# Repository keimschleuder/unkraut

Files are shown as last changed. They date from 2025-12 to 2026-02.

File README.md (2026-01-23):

# Jugend Forscht Unkrautvernichtungsroboter

Wir sind eine Gruppe von 4 Schülern aus Hessen (Deutschland). Wir haben im Rahmen einer Schul-Arbeitsgemeinschaft ein Projekt für den Wettbewerb [Jugend Forscht](https://www.jugend-forscht.de/) erarbeitet. 

## Das Projekt

Wir wollten es mit unserem Roboter ermöglichen, Herbizide und Dünger gezielt einzusetzten. 

Die Hoffnung war, dadurch den Herbizidverbrauch zu reduzieren. 

## Unsere Hardware

Wir verwendeten folgende Produkte: 

<sub>Keine Sponsoren oder sonst irgendwas</sub>

### Für den Raspberry Pi:
* [Raspberry Pi 5 16gb RAM](https://www.berrybase.de/raspberry-pi-5-16gb-ram)
* [Raspberry Pi Active Cooler](https://www.berrybase.de/raspberry-pi-active-cooler-luefter-fuer-raspberry-pi-5)
* [Raspberry Pi AI Camera](https://www.berrybase.de/raspberry-pi-ai-camera)
* [Raspberry Pi 27W Power Supply](https://www.berrybase.de/raspberry-pi-ai-camera)
* [Micro SD Karte](https://www.berrybase.de/sandisk-extreme-pro-microsdxc-a2-uhs-i-u3-v30-200mb-s-speicherkarte-adapter-256gb)

### Motoren und Ansteuerung
* [Arduino Nano](https://www.amazon.de/YELUFT-CH340G-Kompatibel-Arduino-Typ-C-Schnittstelle/dp/B0F5PZXH51)
* [2.2 Ohm 5W Widerstand](https://www.amazon.de/PATIKIL-Widerst%C3%A4nde-Widerstand-Netzadapter-Leiterplatte/dp/B0CS3F67QV)
* [Logic Level Converter](https://www.amazon.de/AZDelivery-TXS0108E-Converter-Arduino-Raspberry/dp/B07N7FFY2Q)
* [Servo-Treiber](https://www.amazon.de/AZDelivery-PCA9685-Servotreiber-Arduino-Raspberry/dp/B072N8G7Y9?th=1)
* [Relais](https://www.amazon.de/AZ822-2C-3DSE-Relais-elektromagnetisch-USpule-120VAC/dp/B01LZZPO4O)

## Schaltplan 

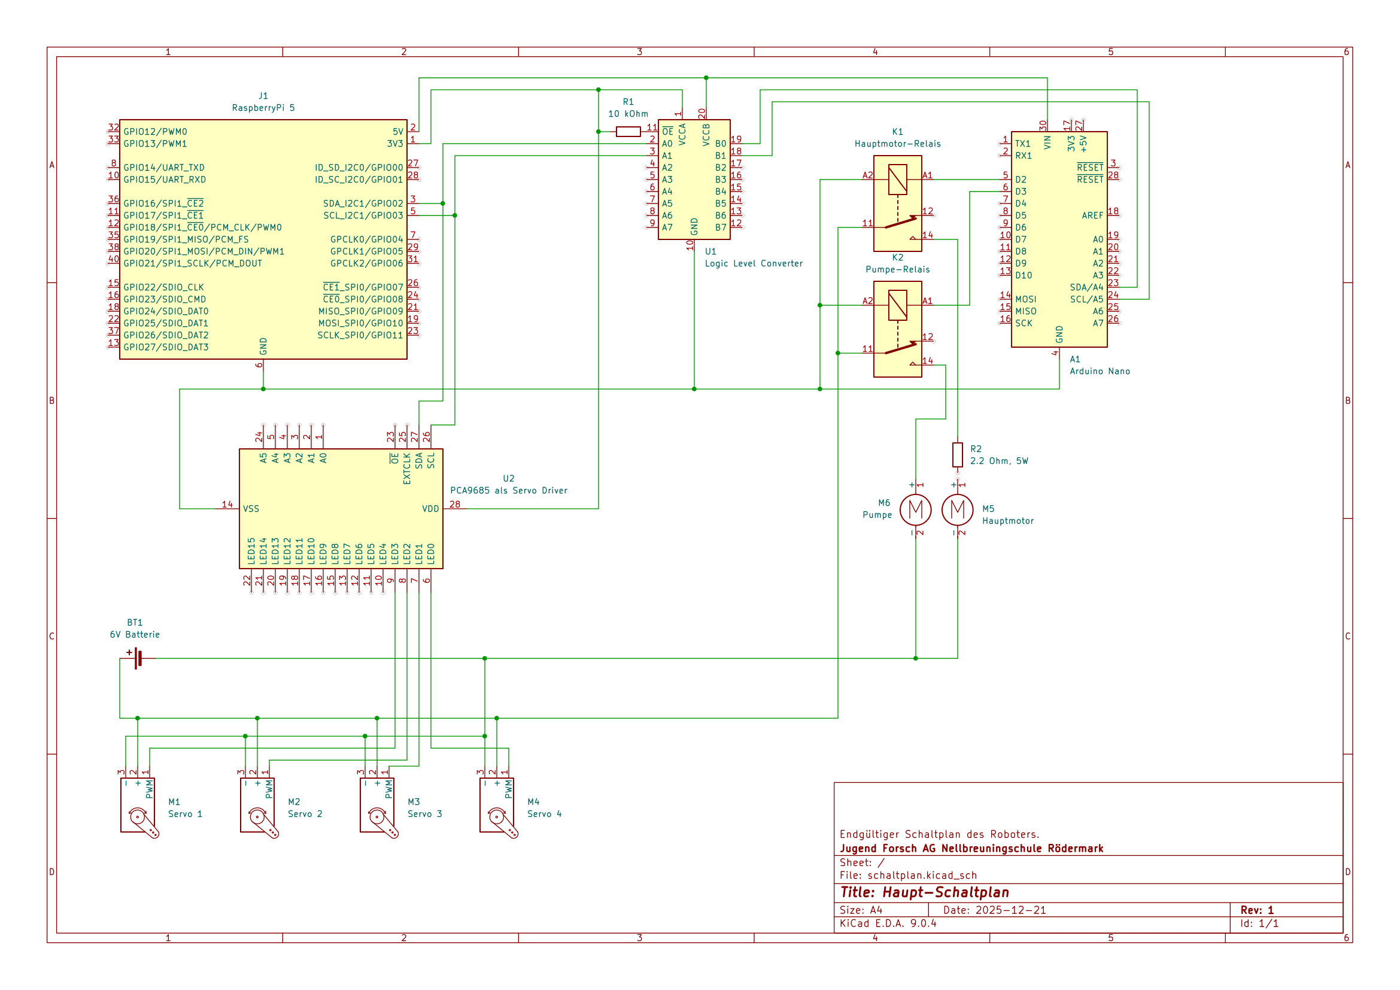
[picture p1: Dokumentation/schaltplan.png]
Schaltplan


## Zu Hause nachbauen

1. Wenn du alle Komponenten hast, installiere Raspbian und Python 3.13 auf dem Raspberry Pi.
2. Installiere diese Python-Erweiterung uaf dem Raspberry Pi:
    * `picamera2`
    * `adafruit_servokit`
    * `requests`
    * `smbus`
3. Lasse [diesen code](/Arduino/main.ino) auf dem Arduino laufen.
4. Verkabele die Komponenten entsprechend des Schaltplanes und schließe die Kamera an den Pi an.
5. Klone das Repository auf denRaspberry Pi.
6. Erstelle dir bei [plantnet](https://my.plantnet.org/) einen Account un einen API-Key. Erstelle dann eine Datei `api_key.py` im Ordner [rpi_drivers](/rpi_drivers) und speichere deinen API-Key in dieser Datei in der Variable `API_KEY` als String.
7. Führe die [main.py](/main.py) auf dem Raspberry Pi aus.

## Plant Recognition

The image-based plant species identification service used, is based on the Pl@ntNet recognition API, regularly updated and accessible through the site https://my.plantnet.org/

Plantnet Logo

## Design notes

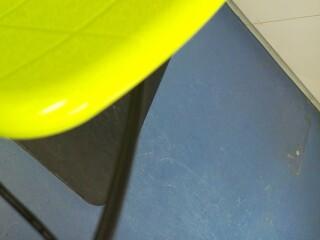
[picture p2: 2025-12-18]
Helpful/captures/1766066036624_q4.jpg

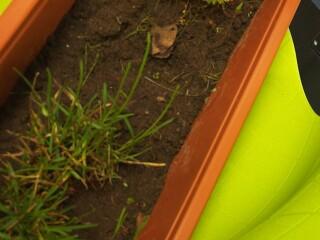
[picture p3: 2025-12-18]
Helpful/captures/1766066066106_q1.jpg

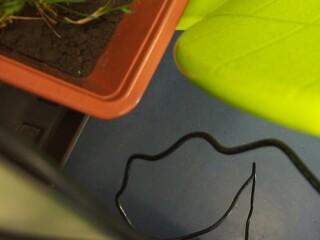
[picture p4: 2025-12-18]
Helpful/captures/1766066036624_q3.jpg

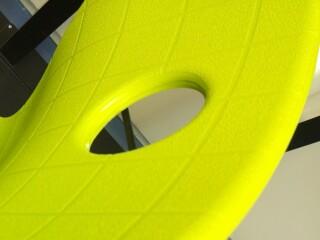
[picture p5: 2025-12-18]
Helpful/captures/1766066066106_q2.jpg

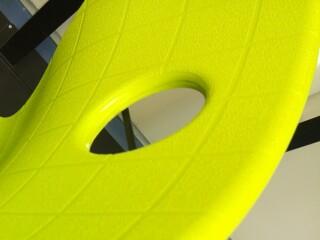
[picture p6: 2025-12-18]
Helpful/captures/1766066036624_q2.jpg

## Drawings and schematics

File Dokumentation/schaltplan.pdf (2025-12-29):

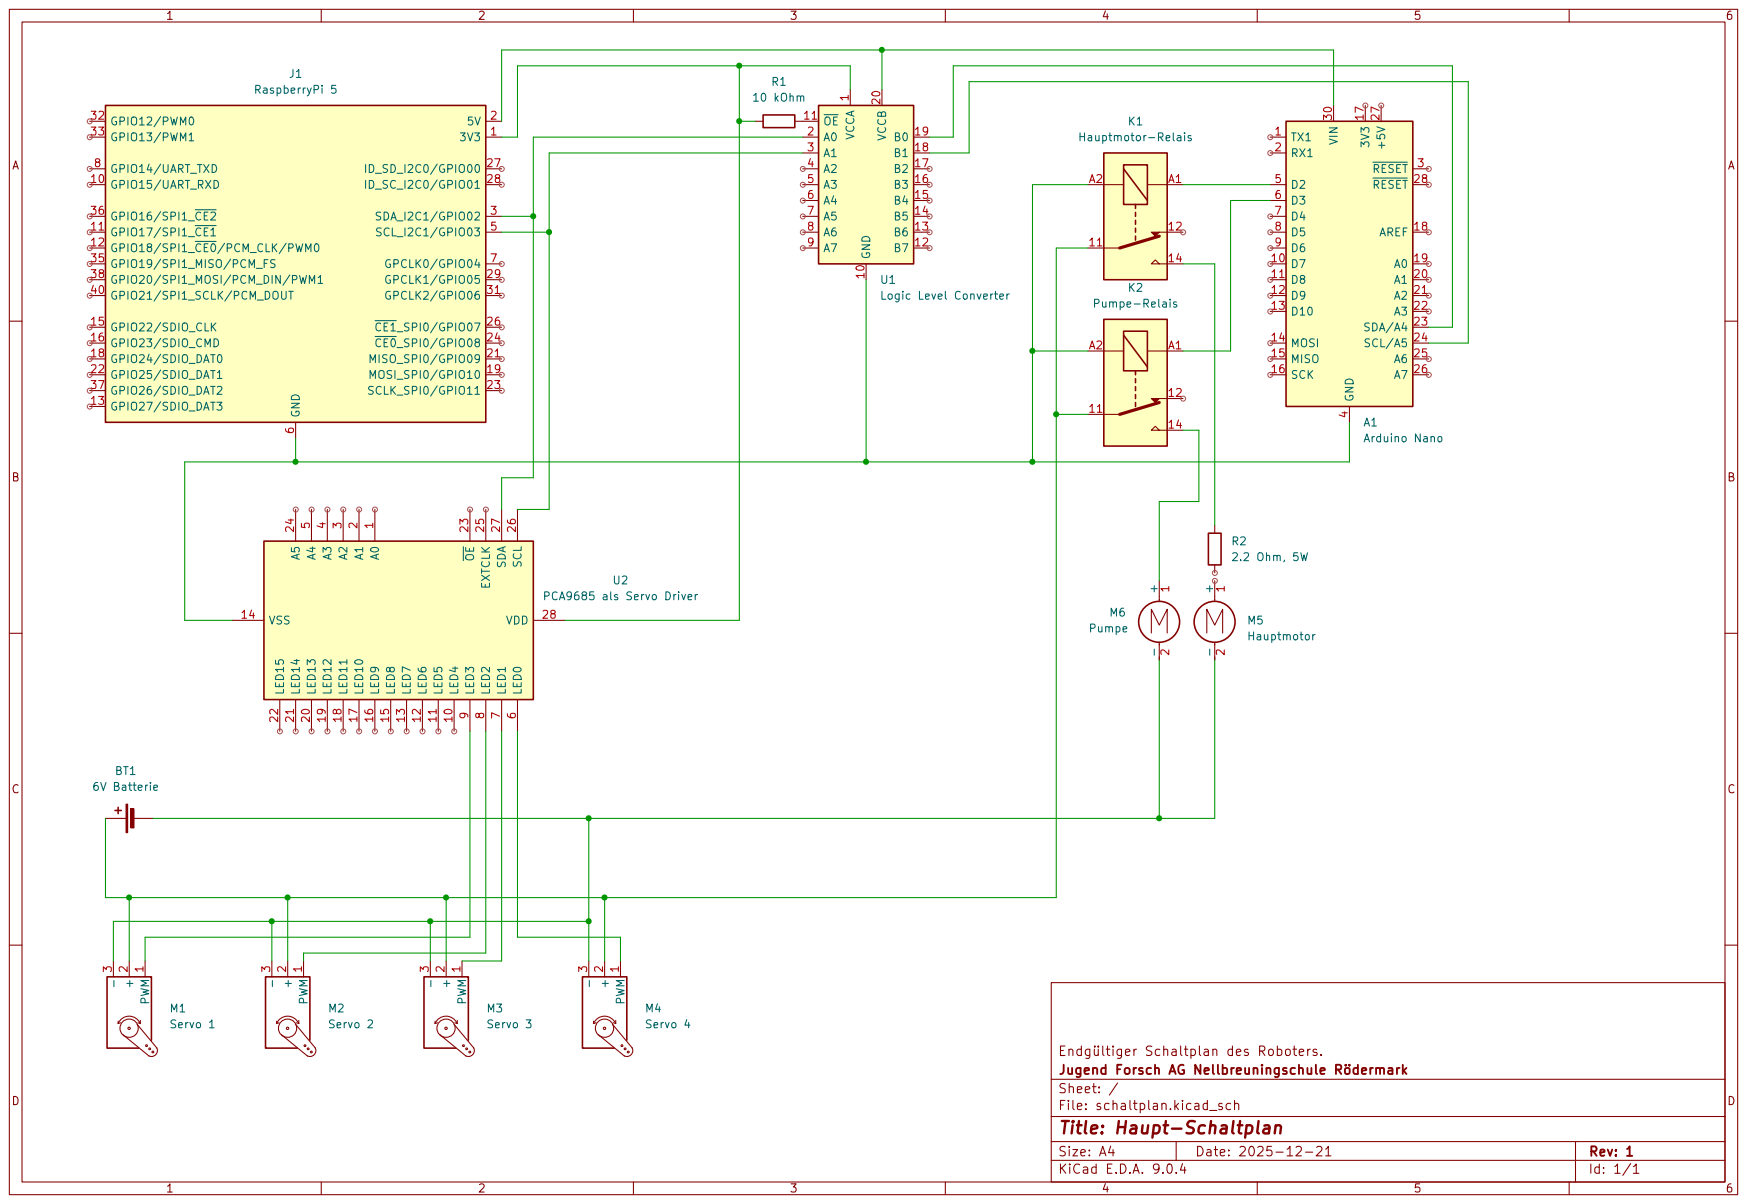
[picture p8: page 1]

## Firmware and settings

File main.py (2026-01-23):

from picamera2 import Picamera2
import io
import os
from PIL import Image
import time
import argparse
import rpi_drivers.arduino
import rpi_drivers.plantnet
import rpi_drivers.servo

# Console Arguments init
parser = argparse.ArgumentParser(prog = "main.py", 
                                 usage = "python main.py [-h]", 
                                 description = "Intended to run on a Raspberry Pi 5 with AI-HAT and AI-Camera. It detects harmful plants and destroys them.", 
                                 epilog = "Program written for the german Jugend Forscht-Competition", 
                                 formatter_class=argparse.ArgumentDefaultsHelpFormatter)

# Driver init
arduino_drv = rpi_drivers.arduino.Arduino()

plantnet_drv = rpi_drivers.plantnet.PlantNet()

roboterarm = rpi_drivers.servo.Servo()

def find_weeds(bestMatches):
    # Evaluate whether a crop is a weed based on a list in the plantnet software driver
    weeds_found = []
    for i, match in enumerate(bestMatches):
        if match is not None:
            for weed in rpi_drivers.plantnet.weeds:
                if match.lower().find(weed) != -1:
                    weeds_found.append([weed, i])
    return weeds_found

def treat_weeds(weeds_found):
    for weed, quadrant in weeds_found:
        print(f"Weed '{weed}' found in quadrant {quadrant + 1}. Treating...")
        match quadrant:
            case 0:
                roboterarm.goto(0, 45)
                roboterarm.goto(1, 135)
            case 1:
                roboterarm.goto(0, 135)
                roboterarm.goto(1, 135)
            case 2:
                roboterarm.goto(0, 45)
                roboterarm.goto(1, 90)
            case 3:
                roboterarm.goto(0, 135)
                roboterarm.goto(1, 90)
        
        arduino_drv.pump(True)
        time.sleep(5)
        arduino_drv.pump(False)

def main():
    # Start Camera
    picam2 = Picamera2()
    picam2.start()
    time.sleep(1)

    for i in range(5):
        # Read image
        data = io.BytesIO()
        picam2.capture_file(data, format='jpeg')

        data.seek(0)
        img = Image.open(data).convert("RGB")
        w, h = img.size
        mx, my = w // 2, h // 2

        # Split into quadrants
        q1 = img.crop((0, 0, mx, my))       # top-left
        q2 = img.crop((mx, 0, w, my))       # top-right
        q3 = img.crop((0, my, mx, h))       # bottom-left
        q4 = img.crop((mx, my, w, h))       # bottom-right

        quadrants = []
        for q in (q1, q2, q3, q4):
            buf = io.BytesIO()
            q.save(buf, format='JPEG')
            buf.seek(0)
            quadrants.append(buf)

        '''
        # Debugging: Save quadrants to files
        output_dir = os.path.join(os.path.dirname(__file__), "captures")
        ts = int(time.time() * 1000)
        for i, q in enumerate((q1, q2, q3, q4), start=1):
            fn = os.path.join(output_dir, f"{ts}_q{i}.jpg")
            q.save(fn, format="JPEG")
        print("Saved quadrants.")
        '''

        # Send the quadrants to the API and process the results
        bestMatches = plantnet_drv.send_multiple_requests(quadrants)
        weeds_found = find_weeds(bestMatches)
        if len(weeds_found) > 0:
            treat_weeds(weeds_found)
            print("All weeds treated")
        else:
            print("No weeds found in this capture.")

        arduino_drv.motor(True)
        time.sleep(1)
        arduino_drv.motor(False)

main()

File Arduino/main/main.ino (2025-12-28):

#include <Wire.h>

#define MOTOR_PIN 2
#define PUMP_PIN 10

byte RxByte;
bool valueMotor = false;
bool valuePump = false;

void I2C_RxHandler(int numBytes)
{
  while(Wire.available()) {  // Read Any Received Data
    RxByte = Wire.read();

    valueMotor = RxByte & 0x01;
    valuePump = RxByte & 0x02;
    
    // Debugging
    Serial.println("Motor "); Serial.println(valueMotor);
    Serial.println("Pump "); Serial.println(valuePump);
  }
}

void setup() {
  Serial.begin(9600);
  pinMode(MOTOR_PIN, OUTPUT);
  Wire.begin(0x2f);
  Wire.onReceive(I2C_RxHandler);
}

void loop() {
  digitalWrite(MOTOR_PIN, valueMotor);
  digitalWrite(PUMP_PIN, valuePump);
  delay(100);
}

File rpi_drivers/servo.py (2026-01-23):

import time
from adafruit_servokit import ServoKit

kit = ServoKit(channels = 16)

class Servo:
    def __init__(self, offset = 0):
        self.servo0 = 0 + offset
        self.servo1 = 1 + offset
        self.servo2 = 2 + offset
        self.servo3 = 3 + offset
        self.offset = offset

    def allGoto(self, value0, value1, value2, value3):
        kit.servo[self.servo0].angle = value0
        kit.servo[self.servo1].angle = value1
        kit.servo[self.servo2].angle = value2
        kit.servo[self.servo3].angle = value3

    def goto(self, servo, value):
        kit.servo[servo + self.offset].angle = value

    def reset(self):
        kit.servo[self.servo0].angle = 90
        kit.servo[self.servo1].angle = 90
        kit.servo[self.servo2].angle = 90
        kit.servo[self.servo3].angle = 90

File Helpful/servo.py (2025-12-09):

# Warning: Make shure to run the "reset"-function for the pan-tilt-kit to work properly
# Warnung: Immer zuerst die "reset"-funktion aufrufen um eine Richtige funktionsweise sicherzustellen

import time
from adafruit_servokit import ServoKit

time.sleep(1)

kit = ServoKit(channels = 16)
kit.servo[0].angle = 45
print(1)
time.sleep(1)
kit.servo[0].angle = 135
print(2)
time.sleep(1)
kit.servo[0].angle = 90
print(3)
time.sleep(1)
kit.servo[1].angle = 180
print(1)
time.sleep(1)
kit.servo[1].angle = 135
print(2)
time.sleep(1)
kit.servo[1].angle = 90
print(3)

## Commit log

2025-09-09 Fehler behoben…
2025-09-11 Added Motor Doku
2025-11-13 unsing an api, we try to avoid training an own ai
    [plantnet-api-test.py]
2025-11-25 making shure he i2c is alwalys turned off
2025-11-28 Writing prototype Drivers for the RPi5 and adding the api key to a file in .gitignore
2025-11-28 writing a GPIO driver for RPi5 All drivers still need testing
2025-12-04 Servo driver arrived
2025-12-09 servo working
2025-12-09 trying to get the camera running
2025-12-22 Adding the code running on the arduino
2025-12-28 Changing the arduino, all the values get transmitted right, output still wrong
    [main.ino]
2025-12-29 Writing more doku
    [schaltplan.kicad_sch]
